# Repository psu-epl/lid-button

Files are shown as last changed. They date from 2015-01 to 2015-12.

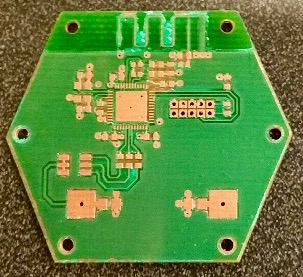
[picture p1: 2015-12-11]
Pictures/SolderMask.jpg

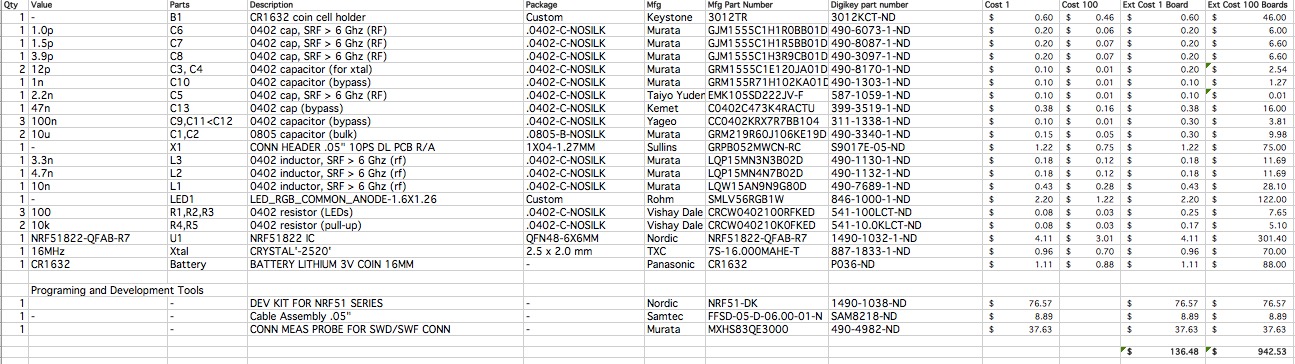
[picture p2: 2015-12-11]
Pictures/PicBillMaterials.jpg

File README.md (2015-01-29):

Mesh network pulsing button for LID grand opening ceremony. Demonstrates cheap interconnected devices.

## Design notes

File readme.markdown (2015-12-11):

LID Disco Button
----
Starting fresh? Go [here](https://github.com/psu-epl/lid-button/wiki)

Quick Links:

[Board Routing](https://github.com/psu-epl/lid-button/wiki/Board-Routing)

[Plating Thru Holes](https://github.com/psu-epl/lid-button/wiki/Plating-Thru-Holes)

[Testing the Board Part One](https://github.com/psu-epl/lid-button/wiki/Testing-the-board-Part-One)

[Solder Mask](https://github.com/psu-epl/lid-button/wiki/Applying-Solder-Mask)

[Solder Paste Stencil](https://github.com/psu-epl/lid-button/wiki/Solder-Paste-Stencil)

[Solder Paste](https://github.com/psu-epl/lid-button/wiki/Solder-Paste-Prep)

[Stuffing the board](https://github.com/psu-epl/lid-button/wiki/Stuffing-the-Board)

[Reflow Oven](https://github.com/psu-epl/lid-button/wiki/Reflow)

[Testing the Board Part Two](https://github.com/psu-epl/lid-button/wiki/Testing-The-Board-Part-Two)

[Programming the Microcontroller](https://github.com/psu-epl/lid-button/wiki/Coding-the-Board)

[Final Board Test](https://github.com/psu-epl/lid-button/wiki/Final-Board-Test)

[Enclosure Bottom](https://github.com/psu-epl/lid-button/wiki/Enclosure-Bottom)

[Enclosure Top](https://github.com/psu-epl/lid-button/wiki/Enclosure-Top)

[About this Project](https://github.com/psu-epl/lid-button/wiki/About-this-Project)

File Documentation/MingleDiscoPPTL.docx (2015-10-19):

Project Proposal

& Timeline

Mingle Disco Button

# Revision Notes

Revision Number | Comments | Date | Author
1.0 | Doc created | 6/24/15 | Kris Gibbs

# Hardware Design

Each piece can be designed in parallel. 4 weeks

## Antenna

- What kind of antenna
- Make board to place rf chip on to test s parameters for matching
- Optimize antenna for 2.4 GHz

## Power management

- Design battery system for optimal battery life
- Consider rechargeable battery

## Board design rework

- Integrate new antenna and battery design into existing board

# Enclosure Design

1 week.

## Button

- 3D printed file

## Name tag

- Laser cutter file

# Software Design

This will coincide with testing. 4 weeks total. Two test/development boards will be made just for this purpose.

## Breathing Led Synchronization

- Code to make Led “Breathe” blink in sync with others in the same room. (how many feet away?)

## Color Mingle

- Code to make led colors mix when in close proximity to another. (How many feet away?)

Other code?

# Manufacturing

1 week.

## Boards

- 3 routed boards made in EPL
- OSH park boards to compare

## Buttons

- 3d printed ( color?)

## Name Tag

- Laser cut acrylic

# Testing

Hardware and software testing to be done in parallel and iteratively. 3 weeks total

## Test Plan

- Antenna
- Power supply
- Software testing

## Test Implementation

- Separate testing boards for each test break out
- Software testing board will have only RF chip and led

# Documentation

To be done as project progresses and finalized at the end of the project. 2 weeks

## Laser Cutter

- Inkscape file

## 3D Printer

- STL file

## Plating Tank

- Basic procedure

## Board Router

- Eagle files

## Reflow Oven

- Basic procedure

## Soldering Station

- Basic procedure

## VNA

- Calibration
- S parameter measurement procedure

[Type text][Type text][Type text]

5 Project Proposal and Timeline

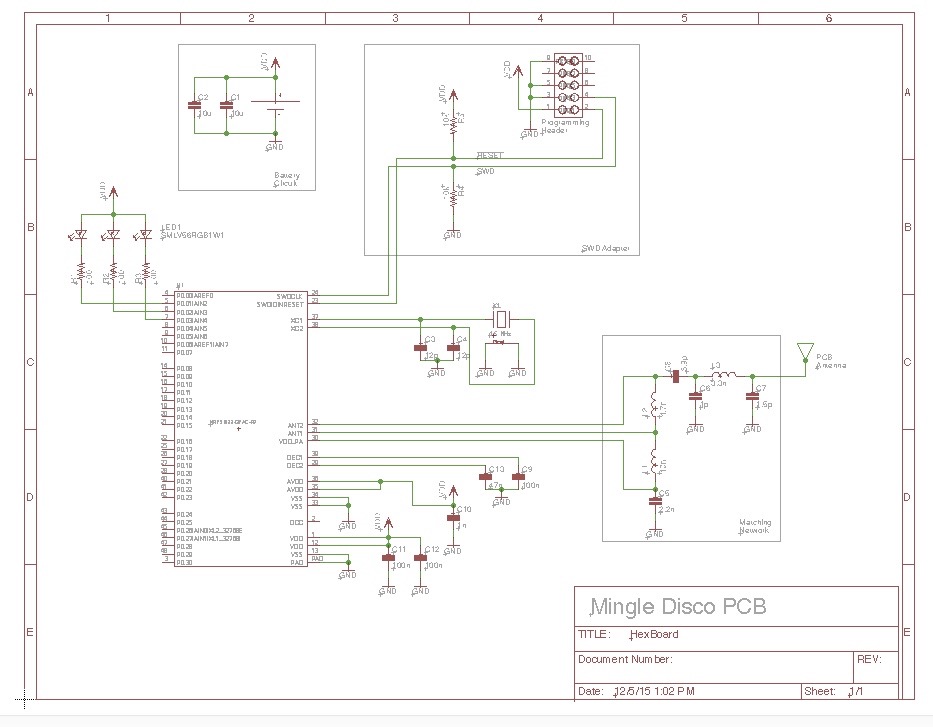
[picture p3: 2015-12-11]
Pictures/Schematic.jpg

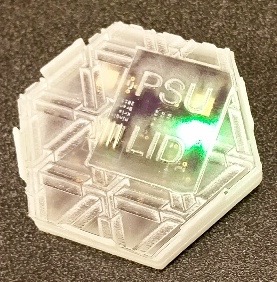
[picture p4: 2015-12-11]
Pictures/MingleDisco.jpg

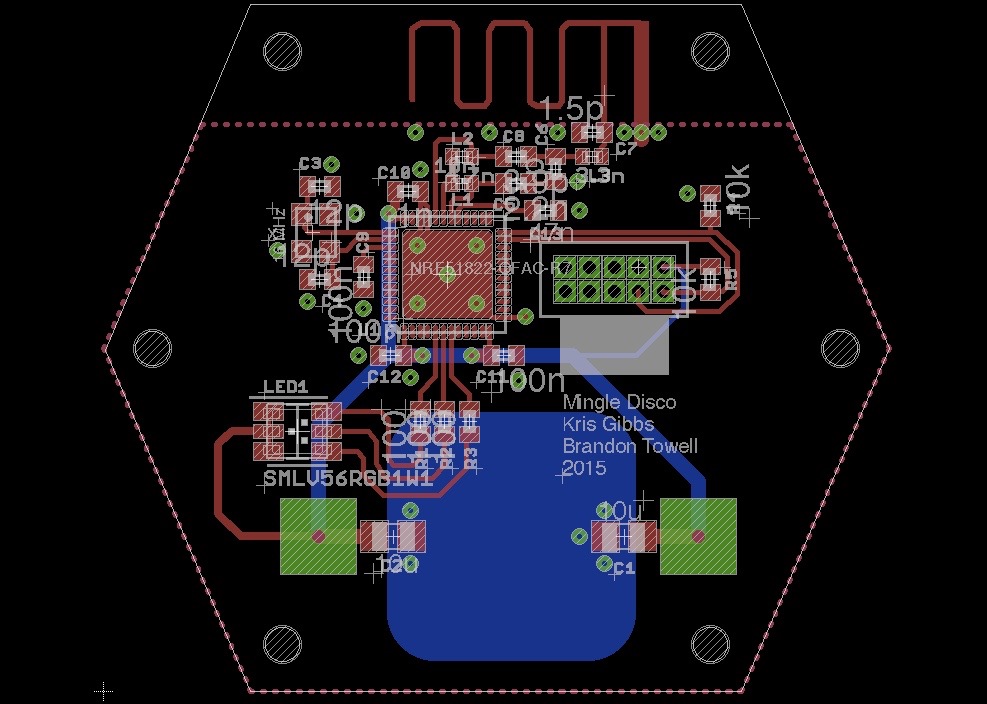
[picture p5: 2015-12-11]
Pictures/Board.jpg

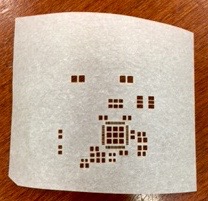
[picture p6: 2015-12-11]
Pictures/Stencil.jpg

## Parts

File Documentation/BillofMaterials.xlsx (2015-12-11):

Qty | Value | Parts | Description | Package | Mfg | Mfg Part Number | Digikey part number | Cost 1 | Cost 100 | Ext Cost 1 Board | Ext Cost 100 Boards
1 | - | B1 | CR1632 coin cell holder | Custom | Keystone | 3012TR | 3012KCT-ND | $0.60 | $0.46 | $0.60 | $46.00
1 | 1.0p | C6 | 0402 cap, SRF > 6 Ghz (RF) | .0402-C-NOSILK | Murata | GJM1555C1H1R0BB01D | 490-6073-1-ND | $0.20 | $0.06 | $0.20 | $6.00
1 | 1.5p | C7 | 0402 cap, SRF > 6 Ghz (RF) | .0402-C-NOSILK | Murata | GJM1555C1H1R5BB01D | 490-8087-1-ND | $0.20 | $0.07 | $0.20 | $6.60
1 | 3.9p | C8 | 0402 cap, SRF > 6 Ghz (RF) | .0402-C-NOSILK | Murata | GJM1555C1H3R9CB01D | 490-3097-1-ND | $0.20 | $0.07 | $0.20 | $6.60
2 | 12p | C3, C4 | 0402 capacitor (for xtal) | .0402-C-NOSILK | Murata | GRM1555C1E120JA01D | 490-8170-1-ND | $0.10 | $0.01 | $0.20 | $2.54
1 | 1n | C10 | 0402 capacitor (bypass) | .0402-C-NOSILK | Murata | GRM155R71H102KA01D | 490-1303-1-ND | $0.10 | $0.01 | $0.10 | $1.27
1 | 2.2n | C5 | 0402 cap, SRF > 6 Ghz (RF) | .0402-C-NOSILK | Taiyo Yuden | EMK105SD222JV-F | 587-1059-1-ND | $0.10 | $0.01 | $0.10 | $0.01
1 | 47n | C13 | 0402 cap (bypass) | .0402-C-NOSILK | Kemet | C0402C473K4RACTU | 399-3519-1-ND | $0.38 | $0.16 | $0.38 | $16.00
3 | 100n | C9,C11<C12 | 0402 capacitor (bypass) | .0402-C-NOSILK | Yageo | CC0402KRX7R7BB104 | 311-1338-1-ND | $0.10 | $0.01 | $0.30 | $3.81
2 | 10u | C1,C2 | 0805 capacitor (bulk) | .0805-B-NOSILK | Murata | GRM219R60J106KE19D | 490-3340-1-ND | $0.15 | $0.05 | $0.30 | $9.98
1 | - | X1 | CONN HEADER .05" 10PS DL PCB R/A | 1X04-1.27MM | Sullins | GRPB052MWCN-RC | S9017E-05-ND | $1.22 | $0.75 | $1.22 | $75.00
1 | 3.3n | L3 | 0402 inductor, SRF > 6 Ghz (rf) | .0402-C-NOSILK | Murata | LQP15MN3N3B02D | 490-1130-1-ND | $0.18 | $0.12 | $0.18 | $11.69
1 | 4.7n | L2 | 0402 inductor, SRF > 6 Ghz (rf) | .0402-C-NOSILK | Murata | LQP15MN4N7B02D | 490-1132-1-ND | $0.18 | $0.12 | $0.18 | $11.69
1 | 10n | L1 | 0402 inductor, SRF > 6 Ghz (rf) | .0402-C-NOSILK | Murata | LQW15AN9N9G80D | 490-7689-1-ND | $0.43 | $0.28 | $0.43 | $28.10
1 | - | LED1 | LED_RGB_COMMON_ANODE-1.6X1.26 | Custom | Rohm | SMLV56RGB1W | 846-1000-1-ND | $2.20 | $1.22 | $2.20 | $122.00
3 | 100 | R1,R2,R3 | 0402 resistor (LEDs) | .0402-C-NOSILK | Vishay Dale | CRCW0402100RFKED | 541-100LCT-ND | $0.08 | $0.03 | $0.25 | $7.65
2 | 10k | R4,R5 | 0402 resistor (pull-up) | .0402-C-NOSILK | Vishay Dale | CRCW040210K0FKED | 541-10.0KLCT-ND | $0.08 | $0.03 | $0.17 | $5.10
1 | NRF51822-QFAB-R7 | U1 | NRF51822 IC | QFN48-6X6MM | Nordic | NRF51822-QFAB-R7 | 1490-1032-1-ND | $4.11 | $3.01 | $4.11 | $301.40
1 | 16MHz | Xtal | CRYSTAL'-2520' | 2.5 x 2.0 mm | TXC | 7S-16.000MAHE-T | 887-1833-1-ND | $0.96 | $0.70 | $0.96 | $70.00
1 | CR1632 | Battery | BATTERY LITHIUM 3V COIN 16MM | - | Panasonic | CR1632 | P036-ND | $1.11 | $0.88 | $1.11 | $88.00
 | Programing and Development Tools
1 |  | - | DEV KIT FOR NRF51 SERIES | - | Nordic | NRF51-DK | 1490-1038-ND | $76.57 |  | $76.57 | $76.57
1 | - | - | Cable Assembly .05" | - | Samtec | FFSD-05-D-06.00-01-N | SAM8218-ND | $8.89 |  | $8.89 | $8.89
1 |  | - | CONN MEAS PROBE FOR SWD/SWF CONN | - | Murata | MXHS83QE3000 | 490-4982-ND | $37.63 |  | $37.63 | $37.63
 |  |  |  |  |  |  |  |  |  | $136.47 | $942.53

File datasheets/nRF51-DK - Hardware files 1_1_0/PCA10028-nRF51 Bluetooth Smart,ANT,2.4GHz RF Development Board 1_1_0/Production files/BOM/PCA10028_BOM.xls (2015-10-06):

Bill of material
PCB: | PCA10028
Version: | 1.1.0
Designator | Value | Description | Footprint Doc | Manufacturer | Manufacturer Part Number
Bat1 | Bat Holder CR2032 | Bat Holder CR2032 SMD | CR2032_HOLDER_SMD | Keystone | 3002
C1, C2, C13, C14 | 12pF | Capacitor, NP0, ±2% | 0402
C3 | 2.2nF | Capacitor, X7R, ±10% | 0402
C4 | 1.0pF | Capacitor, NP0, ±0.1pF | 0402
C5 | 3.9pF | Capacitor, NP0, ±0.1pF | 0402
C6 | 1.5pF | Capacitor, NP0, ±0.1pF | 0402
C7 | 4.7µF | Capacitor, X5R, ±10% | 0603
C8, C11, C18, C19, C21, C24, C25, C26, C27, C28, C29, C32, C34, C35, C36, C38, C39, C40, C41 | 100nF | Capacitor, X7R, ±10% | 0402
C9 | 1.0nF | Capacitor, X7R, ±10% | 0402
C10 | 47nF | Capacitor, X7R, ±10% | 0402
C12, C16, C17 | 1.0µF | Capacitor, X7R, ±10% | 0603
C15 | 1.2pF | Capacitor, NP0, ±0.1pF | 0402
C20, C31, C33 | 10µF | Capacitor, X5R, ±20% | 0603
C22, C23 | 18pF | Capacitor, NP0, ±5% | 0402
C30 | 10nF | Capacitor, X7R, ±10% | 0402
C37 | 10pF | Capacitor, NP0, ±2% | 0402
D1 | SD103ATW-7-F | Surface Mount Schottky Barrier Diode Array | SOT-363 | Diodes Incorporated | SD103ATW-7-F
D2 | PRTR5V0U2X | Ultra low capacitance double rail-to-rail ESD protection diode | SOT-143B | NXP | PRTR5V0U2X
J1 | MM8130-2600 | Coaxial Connector with Switch | COAXIAL-SWF | Murata | MM8130-2600
J2 | MicroUSB-B | MicroUSB-B-SMT | FCI_10118193-0001LF | FCI | 10118193-0001LF
L1 | 4.7nH | Inductor, 160mA, ±0.1nH | 0402 | Murata | LQP15MN4N7B02D
L2 | 27nH | Inductor, 70mA, ±2% | 0402 | Murata | LQP15MN27NG02D
L3 | 3.3nH | Inductor, 190mA, ±0.1nH | 0402 | Murata | LQP15MN3N3B02D
L4 | 10µH | Inductor, 80mA, ±10% | 0603 | Taiyo Yuden | LBMF1608T100K
L5 | 15nH | Inductor, 320mA, ±5% | 0402 | Taiyo Yuden | HK100515NJ-T
LD5 | LTST-C195KGJRKT | Ultra bright AlInGaP Bi-Color LED | LED_DUAL_0606 | Lite-On Inc | LTST-C195KGJRKT
LED 1, LED 2, LED 3, LED 4 | L0805G | LED, SMD, 0805, GREEN | 0805 | ROHM | SML-210PTT86
P1, P3, P6 | Socket 1x8 | Socket 1x8, 2.54mm (100mil), SMD | SOCKET_1x8_SMD | Samtec | SSM-108-F-SV-P-TR
P2 | Socket 1x6 | Socket 1x6, 2.54mm (100mil), SMD | SOCKET_1x6_SMD | Samtec | SSM-106-F-SV-P-TR
P4 | Socket 1x10 | Socket 1x10, 2.54mm (100mil), SMD | SOCKET_1x10_SMD | Samtec | SSM-110-F-SV-P-TR
P5 | Pin Hdr 2x3 | Pin Header 2x3, 2.54mm (100mil) SMD | Molex 15-91-2060 | Molex | 15-91-2060
P7, P9, P12, P20 | Pin List 1x8 | Pin List 1x8, 2.54mm (100mil), SMD | LIST_1x8_SMD
P8 | Pin List 1x6 | Pin List 1x6, 2.54mm (100mil), SMD | LIST_1x6_SMD
P10 | Pin List 1x10 | Pin List 1x10, 2.54mm (100mil), SMD | LIST_1x10_SMD
P11 | Socket 2x3 | Socket 2x3, 2.54mm (100mil), SMD | SOCKET_2x3_SMD-2.54mm-bottom | Samtec | SSM-103-F-DV-P-TR
P13, P15, P17 | Pin Header 2x8 | Pin Header 2x8, 2.54mm (100mil) | HDR_2x8
P14 | Pin Header 2x6 | Pin Header 2x6, 2.54mm (100mil) | HDR_2x6
P16 | Pin Header 2x10 | Pin Header 2x10, 2.54mm (100mil) | HDR_2x10
P18, P19 | FTSH-105 | SAMTEC - CONN HEADER 10POS DUAL .05" SMD KEYING SHROUD | FTSH-105 | Samtec | FTSH-105-01-F-DV-K
P21, P22 | Pin List 1x2, Angled | Pin List 1x2, 2.54mm (100mil), Right Angled, SMD | LIST_ANG_1x2-SMD-2.54MM
Q1, Q2 | FDG6321C | Fairchild, FDG6321C, Dual N & P Channel Digital FET | SC70-6 | Fairchild | FDG6321C
R1, R2, R3, R4, R19, R20 | 220R | Resistor, ±1%, 0.063W | 0402
R5, R8, R9, R10, R11, R12 | 10k | Resistor, ±1%, 0.063W | 0402
R6 | N.C. | Not mounted | 0402
R7, R21, R22, R23, R24 | 4k7 | Resistor, ±1%, 0.063W | 0402
R13, R14 | 39R | Resistor, ±1%, 0.063W | 0402
R15, R16 | 150R | Resistor, ±1%, 0.063W | 0402
R17 | 6k8 | Resistor, ±1%, 0.063W | 0402
R18 | 1k | Resistor, ±1%, 0.063W | 0402
SW1, SW2, SW3, SW4, SW5 | PB SW | ALPS - SKHUALE010 - Tactile Switch, SPNO, SMD, 6.5x6.2x2.5mm | ALPS_SKHUxxx010_WO_GND | Alps | SKHUALE010
SW6 | Switch | SMD slide Switch (ON-ON) | JS202011SCQN | C&K Components | JS202011SCQN
U1 | nRF51422-QFAC | Multi-protocol Bluetooth Low Energy, ANT and 2.4GHz proprietary system-on-chip | QFN-48 | Nordic Semiconductor | nRF51422-QFACAx
U2 | ATSAM3U2CA-AU | IC MCU 32bit 128kB flash 100LQFP | LQFP-100 | Atmel | ATSAM3U2CA-AU
U3 | AP7333-33SAG-7 | 300mA, Low Quiescent Current, Fast Transient Low Dropout Linear Regulator | SOT-23-3 | Diodes Incorporated | AP7333-33SAG-7
X1 | 16MHz | XTAL SMD 2520, 16MHz, 8pF, ±15ppm | BT-XTAL_2520 | NDK | NX2520SA-16MHZ-STD-CSW-5
X2 | 32.768kHz | EPSON TOYOCOM - FC-135 32.768KHZ ±20PPM,9.0PF - CRYSTAL, SM, WATCH | XTAL_3215 | Epson Toyocom | FC-135 32.768KHZ ±20PPM,9.0PF
X3 | 12MHz | XTAL SMD 3225, 12MHz, 18pF, ±30ppm | BT-XTAL_3225 | TXC Corporation | 7M-12.000MAAJ-T

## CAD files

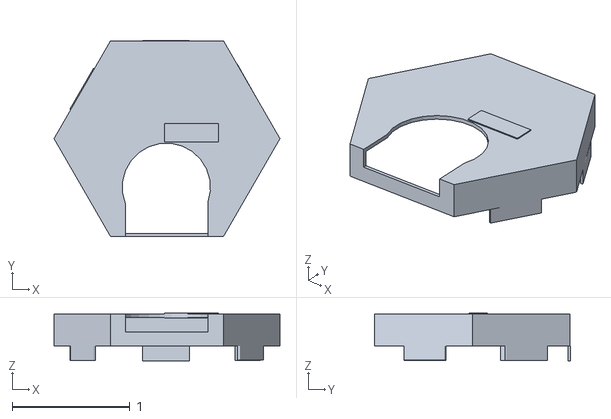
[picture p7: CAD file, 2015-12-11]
Enclosure/HexCaseFinal.stl
1.92 x 1.66 x 0.404

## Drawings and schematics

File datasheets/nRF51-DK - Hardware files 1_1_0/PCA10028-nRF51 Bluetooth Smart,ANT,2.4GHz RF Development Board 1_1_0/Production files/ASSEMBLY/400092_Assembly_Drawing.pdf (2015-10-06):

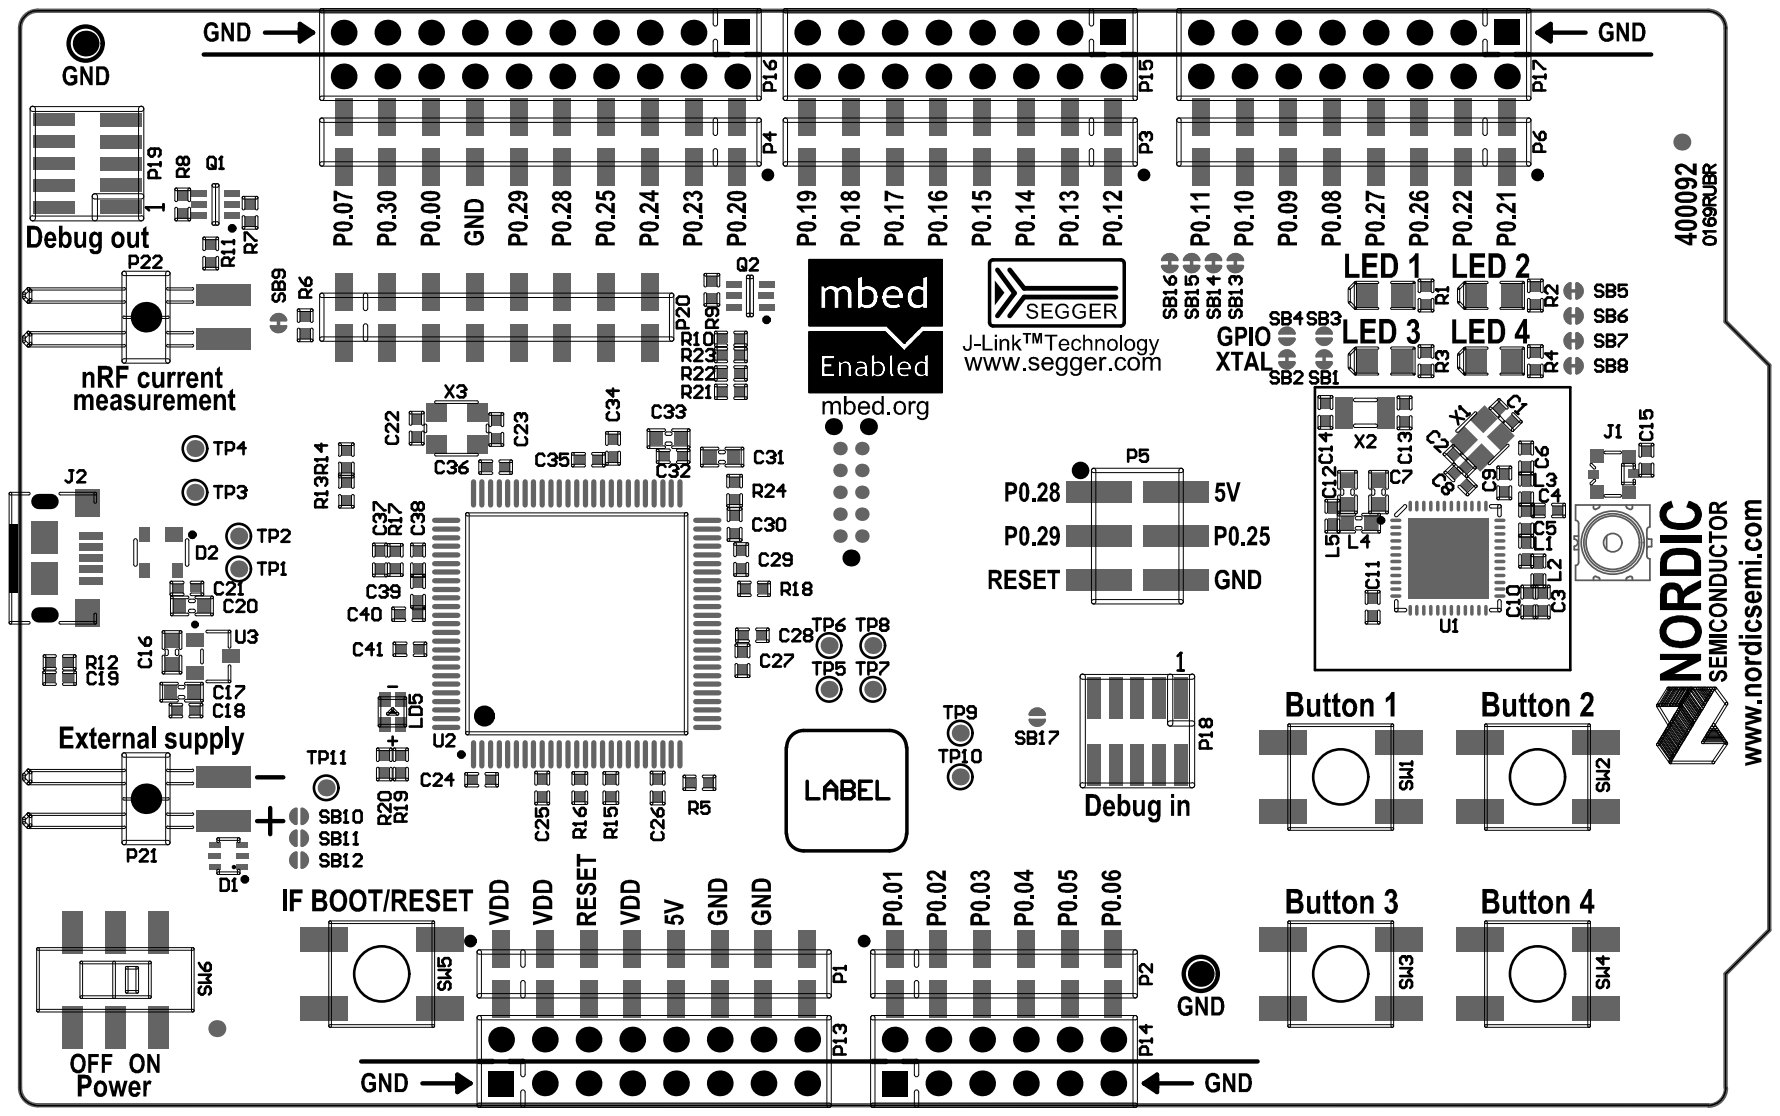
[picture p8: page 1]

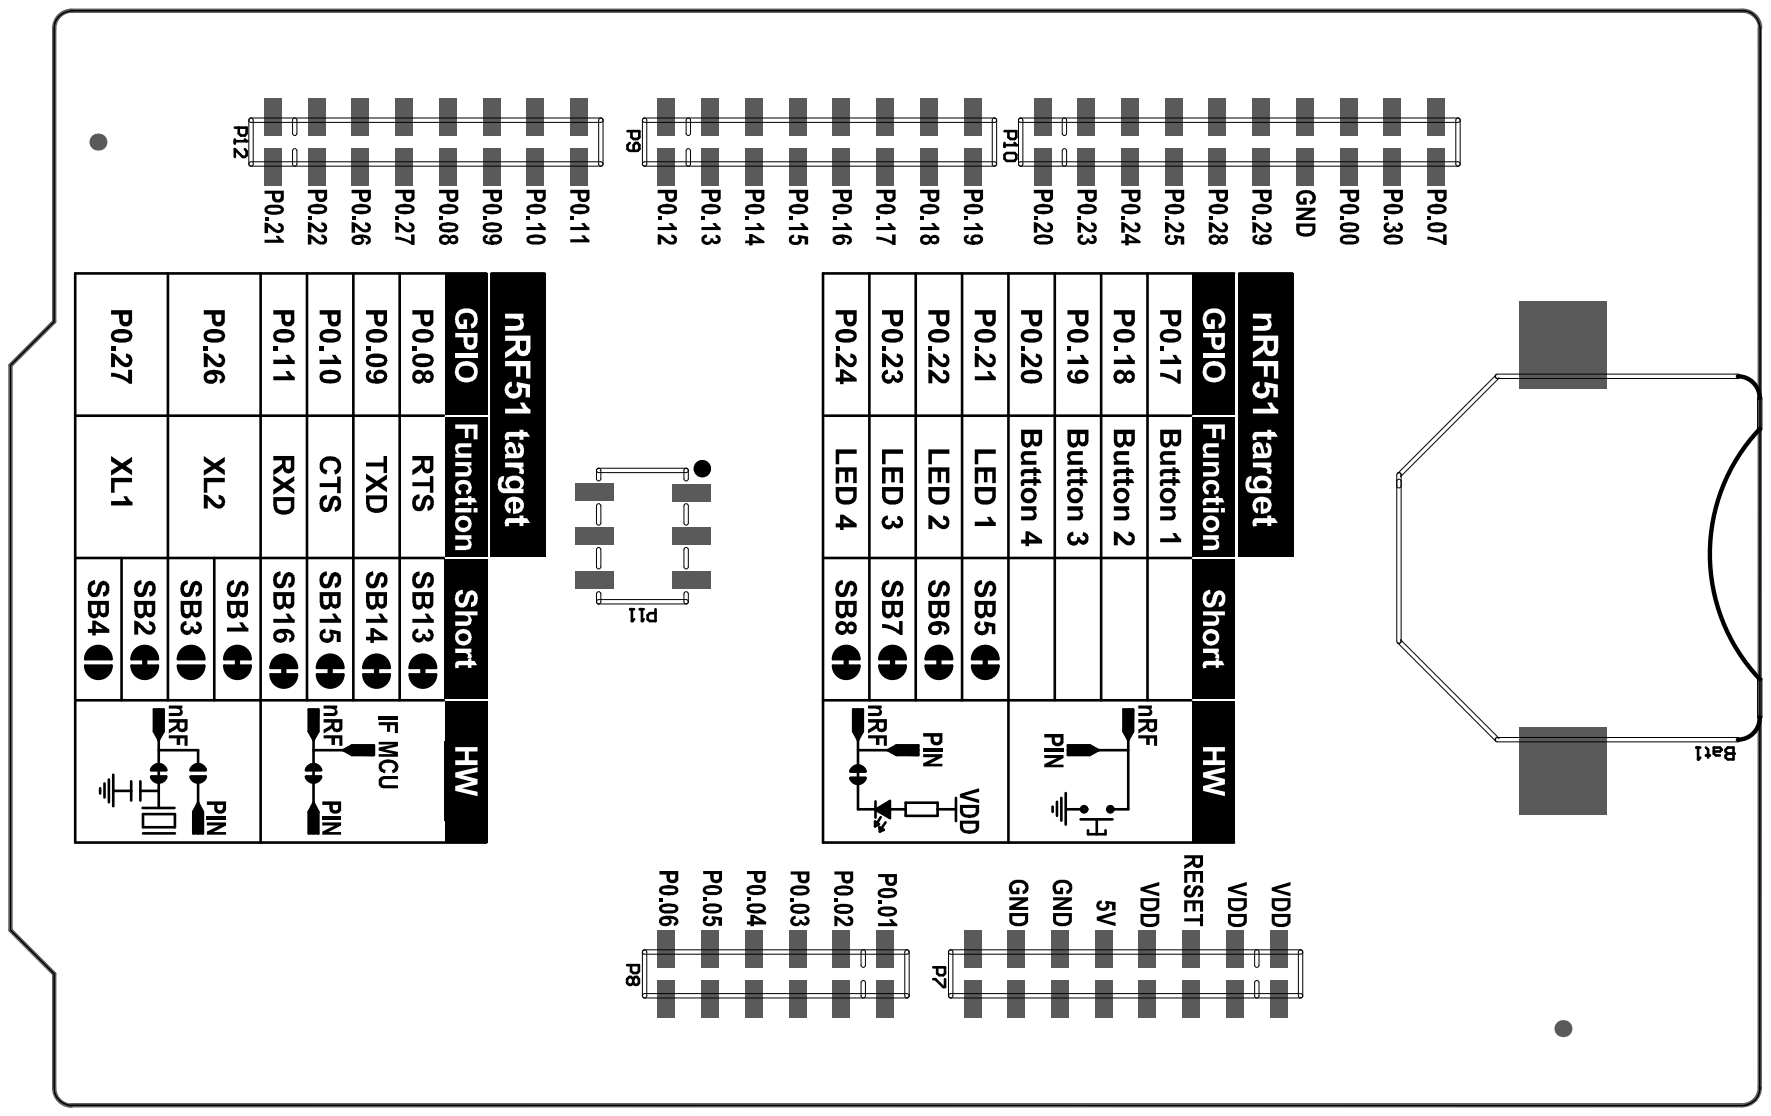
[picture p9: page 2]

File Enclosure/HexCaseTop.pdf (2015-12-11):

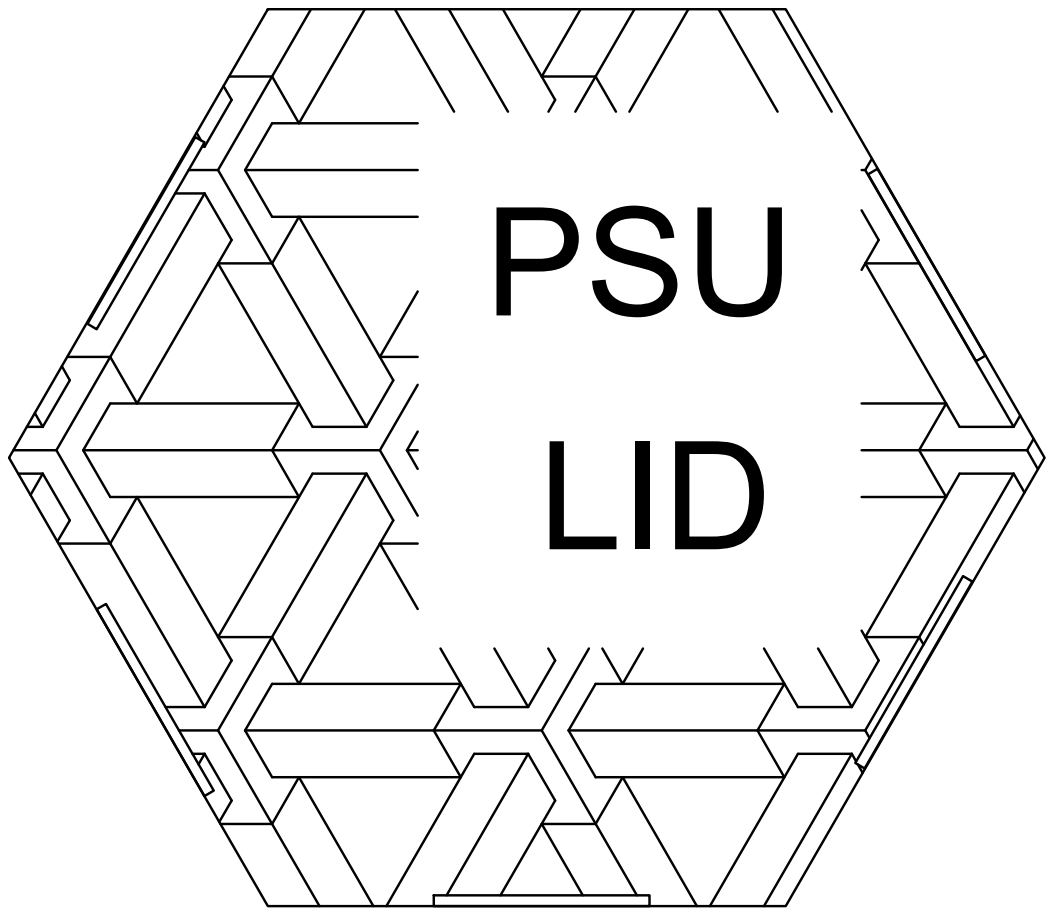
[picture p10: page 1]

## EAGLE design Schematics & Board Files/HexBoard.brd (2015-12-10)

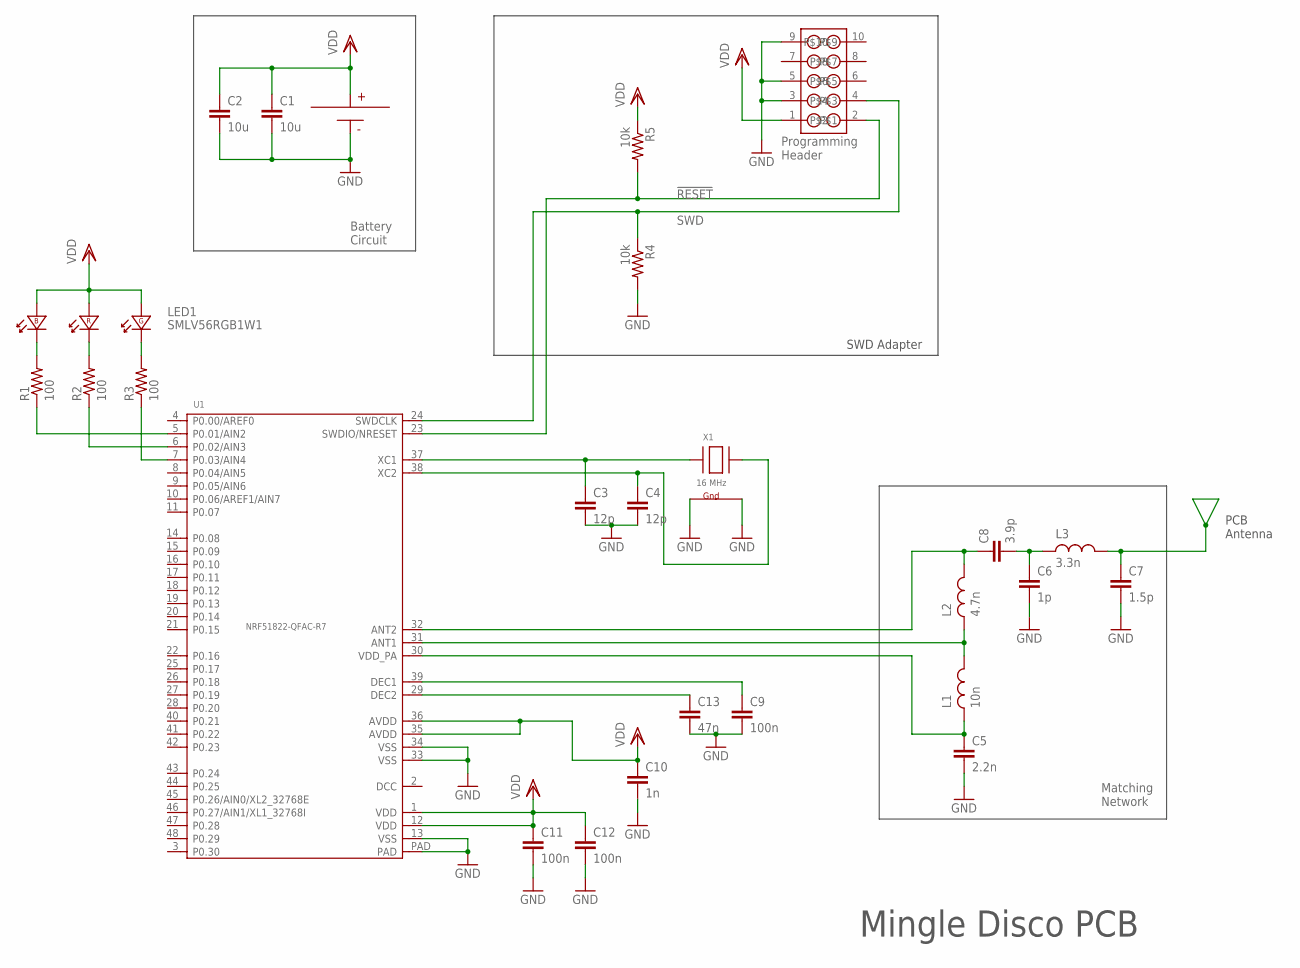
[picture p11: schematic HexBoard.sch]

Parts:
B1: CON-COINCEL-HOLDER-KEYSTONE-3012TR; 16MM-COINCELL-KEYSTONE
C1, C2: 10u; C0805
C3, C4: 12p; C0402
C5: 2.2n; C0402
C6: 1p; C0402
C7: 1.5p; C0402
C8: 3.9p; C0402
C9, C11, C12: 100n; C0402
C10: 1n; C0402
C13: 47n; C0402
L1: 10n; .0402-B-NOSILK
L2: 4.7n; .0402-B-NOSILK
L3: 3.3n; .0402-B-NOSILK
LED1: SMLV56RGB1W1; LED-3528
R1, R2, R3: 100; R0402
R4, R5: 10k; R0402
U1: NRF51822-QFAC-R7; QFN48-6X6MM
U$1: HEADER.05"PITCH
X1: 16 MHz; TXC_CRYSTAL

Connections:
!RESET: R5.2, U1.23 (SWDIO/NRESET), U$1.2
ANTENNA: C7.1, L3.2
GND: B1.NEG, C1.2, C2.2, C3.2, C4.2, C5.2, C6.2, C7.2, C9.2, C10.2, C11.2, C12.2, C13.2, R4.2, U1.13 (VSS), U1.33 (VSS), U1.34 (VSS), U1.PAD, U$1.3, U$1.5, U$1.9, X1.2 (G1), X1.4 (G2)
unnamed: LED1.6 (K), R1.2
unnamed: LED1.5 (K), R2.2
unnamed: LED1.4 (K), R3.2
unnamed: R1.1, U1.5 (P0.01/AIN2)
unnamed: R2.1, U1.6 (P0.02/AIN3)
unnamed: R3.1, U1.7 (P0.03/AIN4)
unnamed: C3.1, U1.37 (XC1), X1.1 (X1)
unnamed: C4.1, U1.38 (XC2), X1.3 (X2)
unnamed: L1.2, L2.1, U1.31 (ANT1)
unnamed: C9.1, U1.39 (DEC1)
unnamed: C6.1, C8.2, L3.1
unnamed: C8.1, L2.2, U1.32 (ANT2)
unnamed: C5.1, L1.1, U1.30 (VDD_PA)
unnamed: C13.1, U1.29 (DEC2)
SWD: R4.1, U1.24 (SWDCLK), U$1.4
VDD: B1.POS@1 (POS), B1.POS@2 (POS), C1.1, C2.1, C10.1, C11.1, C12.1, LED1.1 (A), LED1.2 (A), LED1.3 (A), R5.1, U1.1 (VDD), U1.12 (VDD), U1.35 (AVDD), U1.36 (AVDD), U$1.1

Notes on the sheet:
PCB Antenna
Battery Circuit
Programming Header
Matching Network
SWD Adapter
Mingle Disco PCB

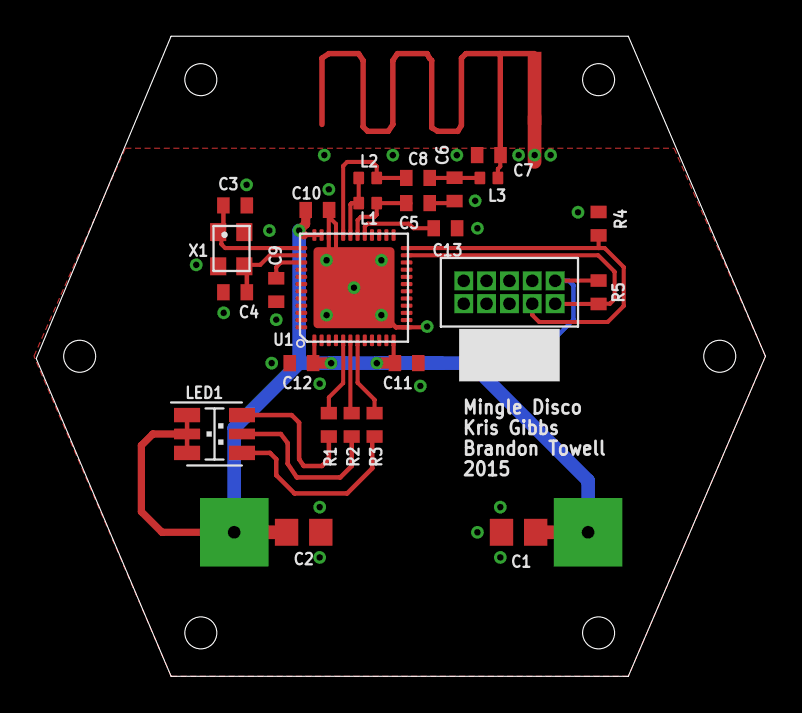
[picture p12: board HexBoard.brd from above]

Board: 2 copper layers, 40.5 x 35.6 mm, 26 parts (1 on the bottom side), 19 nets.

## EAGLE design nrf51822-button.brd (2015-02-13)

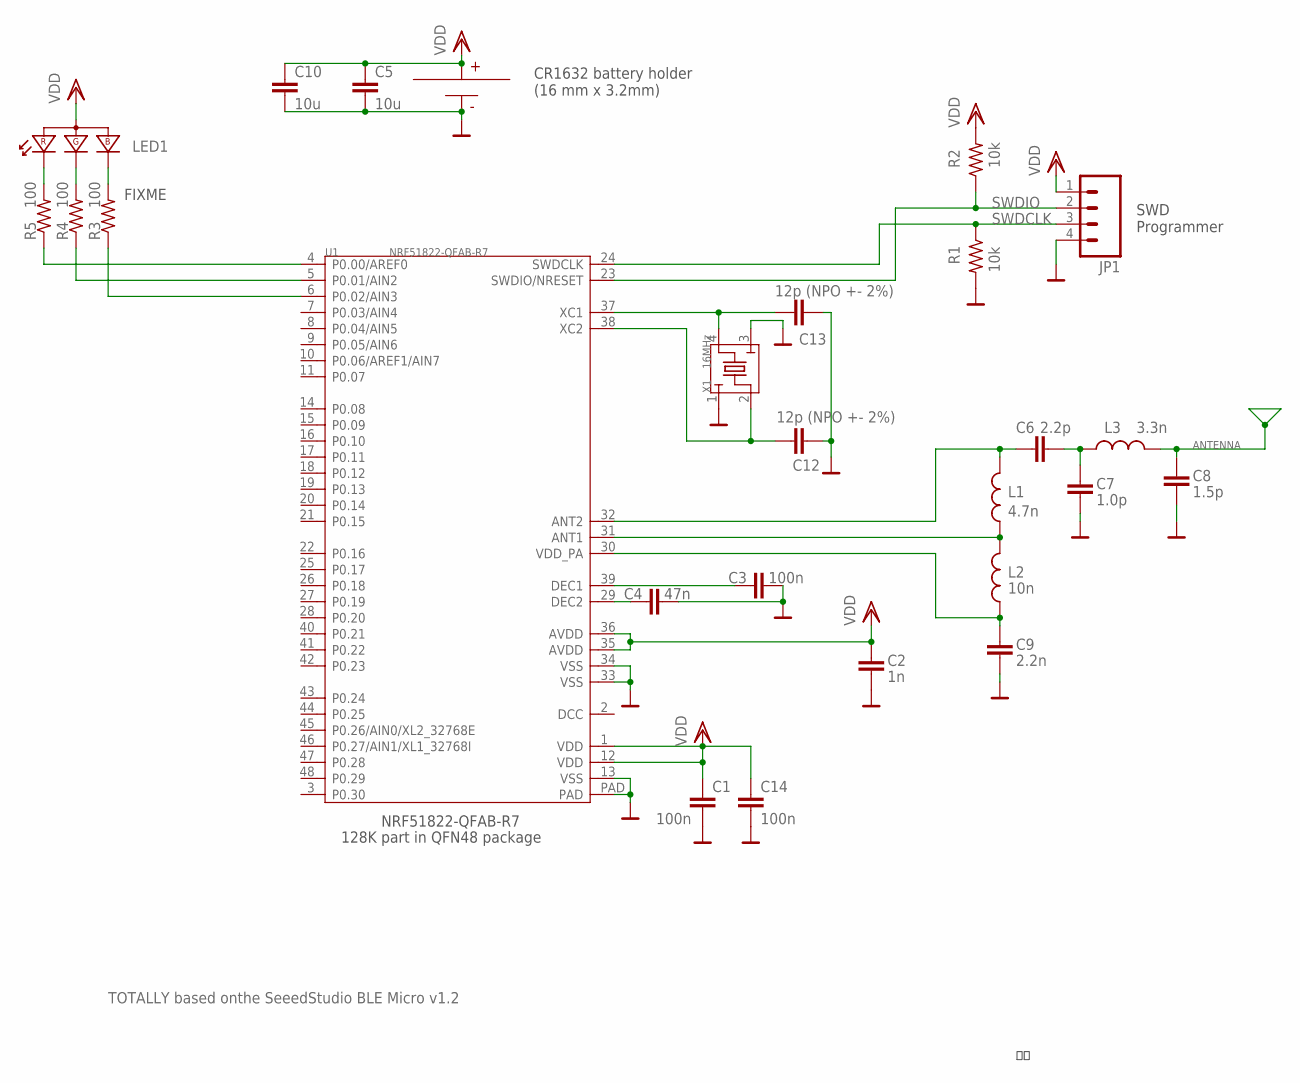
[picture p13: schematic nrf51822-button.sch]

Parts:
B1: CON-COINCEL-HOLDER-KEYSTONE-3012TR; 16MM-COINCELL-KEYSTONE
C1, C3, C14: 100n; .0402-C-NOSILK
C2: 1n; .0402-C-NOSILK
C4: 47n; .0402-C-NOSILK
C5, C10: 10u; .0805-B-NOSILK
C6: 2.2p; .0402-C-NOSILK
C7: 1.0p; .0402-C-NOSILK
C8: 1.5p; .0402-C-NOSILK
C9: 2.2n; .0402-C-NOSILK
C12, C13: 12p (NPO +- 2%); .0402-C-NOSILK
JP1: M041.27MM; 1X04-1.27MM
L1: 4.7n; .0402-C-NOSILK
L2: 10n; .0402-C-NOSILK
L3: 3.3n; .0402-C-NOSILK
LED1: LED_RGB_COMMON_ANODE-1.6X1.26; KINGBRITE_RGBLED_1.6X1.26
R1, R2: 10k; .0402-C-NOSILK
R3, R4, R5: 100; .0402-C-NOSILK
U1: NRF51822-QFAB-R7; QFN48-6X6MM
X1: 16MHz; 2520

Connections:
ANTENNA: C8.2, L3.2
GND: B1.NEG, C1.2, C2.2, C3.2, C4.2, C5.2, C7.1, C8.1, C9.2, C10.2, C12.2, C13.2, C14.2, JP1.4, R1.2, U1.13 (VSS), U1.33 (VSS), U1.34 (VSS), U1.PAD, X1.1, X1.3
unnamed: R5.1, U1.4 (P0.00/AREF0)
unnamed: R4.1, U1.5 (P0.01/AIN2)
unnamed: R3.1, U1.6 (P0.02/AIN3)
unnamed: LED1.3 (RK), R5.2
unnamed: LED1.4 (GK), R4.2
unnamed: LED1.1 (BK), R3.2
unnamed: C13.1, U1.37 (XC1), X1.4
unnamed: C12.1, U1.38 (XC2), X1.2
unnamed: C3.1, U1.39 (DEC1)
unnamed: C4.1, U1.29 (DEC2)
unnamed: C6.1, L1.2, U1.32 (ANT2)
unnamed: L1.1, L2.2, U1.31 (ANT1)
unnamed: C9.1, L2.1, U1.30 (VDD_PA)
unnamed: C6.2, C7.2, L3.1
SWDCLK: JP1.3, R1.1, U1.24 (SWDCLK)
SWDIO: JP1.2, R2.1, U1.23 (SWDIO/NRESET)
VDD: B1.POS@1 (POS), B1.POS@2 (POS), C1.1, C2.1, C5.1, C10.1, C14.1, JP1.1, LED1.2 (COMMON_ANODE), R2.2, U1.1 (VDD), U1.12 (VDD), U1.35 (AVDD), U1.36 (AVDD)

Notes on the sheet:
TOTALLY based onthe SeeedStudio BLE Micro v1.2
CR1632 battery holder (16 mm x 3.2mm)
FIXME
SWD Programmer
NRF51822-QFAB-R7
128K part in QFN48 package

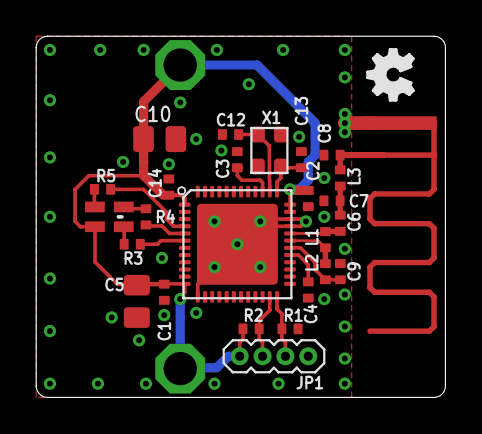
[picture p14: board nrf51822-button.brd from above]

Board: 2 copper layers, 22.7 x 20.1 mm, 27 parts (1 on the bottom side), 19 nets.

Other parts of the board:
U$31: OSHW_FILLX100_NOTEXT

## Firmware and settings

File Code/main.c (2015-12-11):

#include <stdbool.h>
#include <stdio.h>
#include <time.h>
#include <stdint.h>
#include "nrf_delay.h"
#include "nrf_gpio.h"
#include "boards.h"
#include "app_pwm.h"
#include "app_timer.h"
#include <stdlib.h>
#include "SEGGER_RTT.h"

#define LED_B          1
#define LED_R          2
#define LED_G          3
#define PACKET_LENGTH 32

static volatile bool ready_flag; 
int B = 0;
int R = 0;
int G = 0;
int meshy = 0;
int rssi;
uint8_t packet_data[PACKET_LENGTH];
APP_PWM_INSTANCE(PWM_B,0);
APP_PWM_INSTANCE(PWM_R,1);
APP_PWM_INSTANCE(PWM_G,2);

void pwm_ready_callback(uint32_t pwm_id)    
{
  ready_flag = true;
}
void color(int blu,int red, int grn)
{
		app_pwm_channel_duty_set(&PWM_B, 0, blu);
		app_pwm_channel_duty_set(&PWM_G, 0, grn);
		app_pwm_channel_duty_set(&PWM_R, 0, red);
	SEGGER_RTT_printf(0, "Color is set to Blue:%d Red:%d Green:%d\n",blu,red,grn);
}

void led_init()
{
	app_pwm_config_t pwm_cfg_B = APP_PWM_DEFAULT_CONFIG_1CH(5000, LED_B);
	app_pwm_config_t pwm_cfg_R = APP_PWM_DEFAULT_CONFIG_1CH(5000, LED_R);
	app_pwm_config_t pwm_cfg_G = APP_PWM_DEFAULT_CONFIG_1CH(5000, LED_G);
	app_pwm_init(&PWM_B, &pwm_cfg_B,pwm_ready_callback);
	app_pwm_init(&PWM_R, &pwm_cfg_R,pwm_ready_callback);
	app_pwm_init(&PWM_G, &pwm_cfg_G,pwm_ready_callback);
	nrf_gpio_range_cfg_output(1,3);
	app_pwm_enable(&PWM_B);
	app_pwm_enable(&PWM_G);
	app_pwm_enable(&PWM_R);
	color(100,0,0);
	nrf_delay_ms(150);
	color(0,0,100);
	nrf_delay_ms(150);
	color(0,100,0);
	nrf_delay_ms(150);
	
	int colortable [14][3] = {
		{100,0,100} , //Aqua
		{100,0,0} , 	//Blue
		{100,100,0} , //Fuchsia
		{50,50,50} ,	//Grey
		{0,0,50} ,		//Green
		{0,100,0} ,		//Lime
		{0,50,0} ,		//Maroon
		{50,0,0} ,		//Navy
		{0,50,50} ,		//Olive
		{50,50,0} ,		//Purple
		{0,100,0} ,		//Red
		{75,75,75} ,	//Silver
		{50,0,50} ,		//Teal
		{0,100,100} ,	//Yellow
		};
	
	NRF_RNG->TASKS_START = 1;
	NRF_RNG->EVENTS_VALRDY = 0;
	while( NRF_RNG->EVENTS_VALRDY == 0){}	
	int col = NRF_RNG->VALUE % 14;
	SEGGER_RTT_printf(0, "Position %d in table\n",col);
	NRF_RNG->TASKS_STOP = 1;
	B = colortable[col][0];
	R = colortable[col][1];
	G = colortable[col][2];
	color(B,R,G);
}


void blink(int blu,int red, int grn, int cnt, int spd)
{
	while(cnt > 0)
	{
		color(blu,red,grn);
		nrf_delay_ms(spd);
		color(0,0,0);
		nrf_delay_ms(spd);
		cnt--;
	}
}

void mesh(int tblu, int tred, int tgrn, int tsig)
{
	// Do all math in HSV and convert back to RGB/PWM
	meshy = 5;
	int rblu = app_pwm_channel_duty_get(&PWM_B,0);
	int rred = app_pwm_channel_duty_get(&PWM_B,1);
	int rgrn = app_pwm_channel_duty_get(&PWM_G,0);	
	if(abs(tsig) < 65){
		SEGGER_RTT_printf(0, "Meshing\n");
		SEGGER_RTT_printf(0, "Target Blue: %d,Target Red: %d,Target Green: %d\nMy Blue: %d, My Red: %d,My Green: %d\n",tblu,tred,tgrn,rblu,rred,rgrn);
		color((rblu+tblu)/2,(rred+tred)/2,(rgrn+tgrn)/2);	
	}
	rblu = 0; rred = 0; rgrn = 0;
}
void clock_setup(void)
{
  // start 16Mhz external oscillator
  // required for radio peripheral
  NRF_CLOCK->EVENTS_HFCLKSTARTED = 0;
  NRF_CLOCK->TASKS_HFCLKSTART = 1;

  // wait for 16Mhz oscillator to start up
  while( NRF_CLOCK->EVENTS_HFCLKSTARTED == 0 );
}

void radio_setup(uint8_t channel)
{
  NRF_RADIO->POWER        = 1; // enable radio peripheral subsystem

  NRF_RADIO->INTENCLR     = 0xffffffff; // clear all radio interrupts
  
  // Shorts provide a way to automatically trigger a task in response to an event
  // causing a state transision to happen in the radio.  Refer to the state diagram 
  // (fig 22) in the reference manual.  For this example we will not use shorts.
  NRF_RADIO->SHORTS       = 0;

  NRF_RADIO->TXPOWER      = 0; // 0 dBm
  NRF_RADIO->MODE         = RADIO_MODE_MODE_Nrf_2Mbit;

  // Set packet parameters for S0, LENGTH, and S1
  // for custom protocols with fixed packet lengths these are not needed
  NRF_RADIO->PCNF0        = 0;

  // Set packet parameters for length and endianess
  // in this example it is a staticly defined packet length with a 3 byte 
  // address (2 base, 1 prefix)
  NRF_RADIO->PCNF1        = (PACKET_LENGTH << RADIO_PCNF1_MAXLEN_Pos) |
                            (PACKET_LENGTH << RADIO_PCNF1_STATLEN_Pos) |
                            (2 << RADIO_PCNF1_BALEN_Pos);

  // Set the base address and prefix for the radio.  In this example all devices 
  // will have the same address allowing packet transmissions to be broadcast to 
  // multiple devices.  If you were employing a point to point protocol these 
  // addresses may be unique.
  //
  // NOTE: it is recomended to not use 0 or 0xffffffff since they have no bit 
  // transitions making it harder for the radio to distinquish valid packets from 
  // noise.  It is also not recomended to use 0xaa or 0x55 since they can be seen as a continuation of the preamble and cause problems.  This may not be explicitly 
  // discussed in the nrf51 docs but is mentioned in previous nrf chip docs that 
  // use the same on air protocol structure.
  NRF_RADIO->BASE0        = 0x4c494c49; // ascii LILI
  NRF_RADIO->BASE1        = 0x4c494c49;
  NRF_RADIO->PREFIX0      = 0x44444444; // ascii DDDD, combined make LID ;)
  NRF_RADIO->PREFIX1      = 0x44444444;
  NRF_RADIO->TXADDRESS    = 0; // select which address we are using for TX
  NRF_RADIO->RXADDRESSES  = 0x00000001; // only use first address for RX

  // setup crc polynomial and size
  NRF_RADIO->CRCCNF       = (RADIO_CRCCNF_LEN_Two << RADIO_CRCCNF_LEN_Pos);
  NRF_RADIO->CRCPOLY      = 0x1021; // x^12^x^5+1
  NRF_RADIO->CRCINIT      = 0xffff;

  NRF_RADIO->FREQUENCY    = channel; // 2400 Mhz + channel in 1Mhz steps
	SEGGER_RTT_printf(0, "240%d Mhz\n", channel);
}

void radio_transmit( uint8_t * packet_buffer )
{
  //Get current LED data
	packet_data[0] = app_pwm_channel_duty_get(&PWM_B,0);
	packet_data[1] = app_pwm_channel_duty_get(&PWM_R,0);
	packet_data[2] = app_pwm_channel_duty_get(&PWM_G,0);
	// For this example the function will block until the packet has completed transmitting
  // Make sure radio is in disabled state
  NRF_RADIO->EVENTS_DISABLED = 0;
  NRF_RADIO->TASKS_DISABLE = 1;
  while( NRF_RADIO->EVENTS_DISABLED == 0 );

  // set pointer to packet data read using radio peripherals DMA
  NRF_RADIO->PACKETPTR = (uint32_t)packet_buffer;

  // The following tasks can be simplified using shorts but for this example we
  // are doing this explicitly for educational value.  Refer to fig 22 in the 
  // reference manual.

  // turn on transmitter
  NRF_RADIO->EVENTS_READY = 0;
  NRF_RADIO->TASKS_TXEN = 1;
  while( NRF_RADIO->EVENTS_READY == 0 ); // wait for radio to startup ~132us

  // start packet transmission
  NRF_RADIO->EVENTS_END = 0;
  NRF_RADIO->TASKS_START = 1;
  while( NRF_RADIO->EVENTS_END == 0 ); // wait for radio to finish sending packet

  // disable radio
  NRF_RADIO->EVENTS_DISABLED = 0;
  NRF_RADIO->TASKS_DISABLE = 1;
  while( NRF_RADIO->EVENTS_DISABLED == 0 );
	//Return to previous color
	//color(B,R,G);
}

bool radio_receive( uint8_t * packet_buffer )
{
  // For this example the function will block until a packet is received
  // The return value will be true if the packet was valid, false otherwise
  
  // Make sure radio is in disabled state
  NRF_RADIO->EVENTS_DISABLED = 0;
  NRF_RADIO->TASKS_DISABLE = 1;
  while( NRF_RADIO->EVENTS_DISABLED == 0 );

  // set pointer to packet data written to using radio peripherals DMA
  NRF_RADIO->PACKETPTR = (uint32_t)packet_buffer;
	NRF_RADIO->SHORTS |= RADIO_SHORTS_ADDRESS_RSSISTART_Msk;
  // The following tasks can be simplified using shorts but for this example we
  // are doing this explicitly for educational value.  Refer to fig 22 in the 
  // reference manual.
	
  // turn on receiver
  NRF_RADIO->EVENTS_READY = 0;
  NRF_RADIO->TASKS_RXEN = 1;
  while( NRF_RADIO->EVENTS_READY == 0 ); // wait for radio to startup ~132us

  // start listening for packet
  NRF_RADIO->EVENTS_END = 0;
	NRF_RADIO->EVENTS_RSSIEND = 0;
	NRF_RADIO->TASKS_RSSISTART = 1;
  NRF_RADIO->TASKS_START = 1;
  while( NRF_RADIO->EVENTS_END == 0 ); // wait for radio to finish decoding a packet
	rssi = (NRF_RADIO->RSSISAMPLE & RADIO_RSSISAMPLE_RSSISAMPLE_Msk);


  // disable radio
	NRF_RADIO->EVENTS_RSSIEND = 0;
  NRF_RADIO->EVENTS_DISABLED = 0;
  NRF_RADIO->TASKS_DISABLE = 1;
  while( NRF_RADIO->EVENTS_DISABLED == 0 );

  // Since the packet received could be good or bad we need to check the crc
  if( NRF_RADIO->CRCSTATUS != 0 )
  {
    return true;
  }
  else
  {
    // packet data is invalid
    return false;
  }
}
int main(void)
{
	int self = 0;
	SEGGER_RTT_printf(0, "Starting LED\n");
	led_init();
	SEGGER_RTT_printf(0, "Done!\n");
	SEGGER_RTT_printf(0, "Booting up at ");
	clock_setup();
	radio_setup(1);
	SEGGER_RTT_printf(0, "Done!\n");
	
	while(true){
		NRF_RNG->TASKS_START = 1;
		NRF_RNG->EVENTS_VALRDY = 0;
		while( NRF_RNG->EVENTS_VALRDY == 0){}	
		self++;
		nrf_delay_ms(NRF_RNG->VALUE % 250 + 250);
		SEGGER_RTT_printf(0, "Delaying %d\n",NRF_RNG->VALUE % 250 + 250);
		radio_transmit(packet_data);
		nrf_delay_ms(100);
		if(radio_receive(packet_data)){
			if(rssi < 65)
				self = 0;
			if (meshy < 1)
					mesh(packet_data[0],packet_data[1],packet_data[2],rssi);
			else
				meshy--;
		}
		SEGGER_RTT_printf(0, "RSSI:%d\n",rssi);
		if (self > 5){
			self = 0;
			color(B,R,G);
		}
	}
}

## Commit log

2015-01-29 creating lid-button repo!
    [nrf51822-button.brd, nrf51822-button.sch]
2015-01-31 Clean up! This might acutally work (!). Removd 32KHz crystal, added 20 uF of bulk cap for spikes (might need more?). Biggest problem: antenna ok? Do we need the DC-DC converter to reduce the current 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
    [nrf51822-button.brd, nrf51822-button.sch]
2015-01-31 First pass at BOM.
    [nrf51822-button.xlsx]
2015-02-13 Final board cleanup, including checking values and packages. Routed this one as a prototype on the A406. Also added BOM.
    [nrf51822-button.brd, nrf51822-button.sch, nrf51822-button.xlsx]
2015-07-10 Broke out libraries that we used to make the board.
2015-07-15 Added RGB footprint. Made a datasheet directory.
2015-09-15 Adding Brd and such files for Button board update
    [Button.brd, Button.sch]
2015-09-15 lasted version of brd and such
    [Button.brd, Button.sch]
2015-10-06 new board design
    New board design Libraries included
    [400092.DRL, 400092.GBL, 400092.GBO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]
2015-10-19 Folder reassignments
    [Button.brd, Button.dwg, HexBoard.brd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]
2015-10-19 New board design
    [HexBoard.brd, HexBoard.sch]
2015-11-02 Board and schematic cleanup; see email to Kris today for notes.
    [HexBoard.brd, HexBoard.sch]
2015-11-03 new project and main code
    [nrf51822-button.xlsx]
2015-11-03 Schematic clean up
    [HexBoard.brd, HexBoard.sch]
2015-11-04 reverted HexBoard to previous version
    [HexBoard.brd, HexBoard.sch]
2015-11-05 Latest code latest board and schematic updated maker guide
    [HexBoard.brd, HexBoard.sch]
2015-11-16 OCD cleaned up of schematic -- nothing different, just prettyness. Cleaned up TNAMES layer a bit on board, checked DRC, moved a few vias... it's good to go. Sending off to OSH Parkgit add HexBoard.br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
    [HexBoard.brd, HexBoard.sch]
2015-12-05 Merge remote-tracking branch 'origin/master'
    Conflicts:
    Schematics & Board Files/HexBoard.brd
    [Button.brd, HexBoard.brd, HexBoard.sch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]
2015-12-10 Files from Kris.
    [HexBoard.brd, HexBoard.sch]
2015-12-11 added pictures and case stl file
    [HexCaseFinal.stl]
2015-12-11 Edit BOM
    [nrf51822-button.xlsx]
2015-12-11 Changed name of file
    [BillofMaterials.xlsx]
2015-12-11 Added enclosure files
    [Button.dwg]

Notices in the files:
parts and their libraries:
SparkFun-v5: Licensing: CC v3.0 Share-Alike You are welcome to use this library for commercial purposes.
